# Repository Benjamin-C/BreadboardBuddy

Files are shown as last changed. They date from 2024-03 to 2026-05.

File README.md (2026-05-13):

# Breadboard Buddy

An RP2040 microcontroller designed to fit neatly on the end of a breadboard

Important: Some software features listed here are not yet implemented. Run the `help` command to see the commands actually implemented in the current firmware version

# Specs
### Power
| Parameter | | Min | Typ | Max | Unit |
|---|-----|-----|-----|-----|---|
| Input Voltage  | USB | | 5 | | V |
| | EXT | 5 | 12  | 30  | V |
| | AIN | 0 | | 3.3 | V |
| | GPIO| 0 | | 3.3 | V |
| Input Current  | USB | | | 0.5 | A |
| | EXT | | | 2 | A |
| | GPIO| | | 10  | mA |
| Output Voltage | 3v3 | | 3.3 | | V |
| | 3v3A| | 3.3 | | V |
| | GPIO| 0 | | 3.3 | V |
| Output Current | 3v3 | 0.5 | | 2 | A |
| | GPIO| | | 10  | mA |

### System
* Microcontroller: RP2040
* Flash: 2MB

### Peripherals
* 16 GPIO pins capable of input with pull up/down and constant or PWM output.
* 4 analog inputs
* 1 LED connected to GPIO16
* 1 barrel jack switch connected to GPIO17
* 1 button connected to GPIO18

# Setup

## Wiring
Connect the Breadboard Buddy to a breadboard's power rails. Ensure that the positive and negative outputs go to the red and blue sides of each rail. Connect external circuitry to the GPIO or analog pins. If you are doing a lot of analog circuitry, you may with to configure the right rail to be disconnected and manually connect 3v3A there instead. If you are using any voltage higher than 3.3V in your circuit, ensure that it can not reach any of the input pins to the microcontroller.

Connect the USB port of the Breadboard Buddy to your computer, and open and connect your favorite serial monitor.

## Configuration

The right power rail can be configured to output 3v3, EXT, or USB by moving the jumper near the barrel jack. Removing this jumper disconnects that power rail.

Each pin that you want to be an output will have to be explicitly set up as such by using the `mode` command. GPIO pins can be set up as digital inputs or outputs, or PWM outputs. Analog pins can only be set up as analog inputs.

## Firmware
The Breadboard Buddy firmware runs on CircuitPython. To Install it:
1. Download CircuitPython for the Raspberry Pi Pico from https://circuitpython.org/board/raspberry_pi_pico/
2. Connect the Breadboard Buddy to your computer. Disconnect anything else from the Breadboard Buddy.
3. Press and hold the `Reset` button, then press and hold the `Boot` button
4. Release the `Reset` button then release the `Boot` button.
5. The Breadboard buddy should appear as a USB mass storage device named `RPI-RP2`. If this does not happen, try steps 3 and 4 again, waiting longer between actions. If the issue precisest, you have an issue with your hardware.
6. Copy CircuitPython file `adafruit-circuitpython-raspberry_pi_pico-en_US-<version>.uf2` onto the Breadboard Buddy. It should reboot when this is complete.
7. The Breadboard Buddy should now appear as a USB mass storage device named `CIRCUITPY`. If this does not happen, try again from step 3. If the issue precisest, you have an issue with your hardware.
8. Copy `code.py` from `firmware` onto the Breadboard Buddy. The Breadboard Buddy should blink its light several times. You have now installed the Breadboard Buddy firmware.

It is possible to run other software on the Breadboard Buddy either through CircuitPython or by flashing it yourself. This guide will not help you with that.

# Usage

The Breadboard Buddy is interfaced with by sending commands over serial and reading their response.

## Command Types
There are two forms of commands, questions and instructions.
### Instructions
An instruction tells the Breadboard Buddy to do something. This could be to change a configuration field, or set an output value. Most instructions will take the form `<instruction> <field> <value>`. If no value is provided, the command will be assumed to be a question.
### Questions
Questions are asked in the form `<question>[?] <field>`. While the question mark is not required, it is encouraged since any command given with a question mark will be interpreted as a question, even if values are given (in which case they will be ignored).

## Pins
### Pin Fields
For commands that take a pin as a field, there are several ways the pin can be specified. 
#### By number
Pins can be specified by number. Digital pins are 0-15. Analog pins are  ain0-ain4. Example: `5`, `12`, `3`, `ain2`
#### By Name
Pins can also be set up to be identified by a name. Names can be used in place of numbers. Names must be unique for each pin, and each pin can only have 1 alias. Names may contain letters and numbers, but no dashes, spaces, or other characters. Names must start with a letter. Names are not case sensitive, but the given case is stored. Example: `LED`, `BitClk`, `Q`, `Addr2`
#### By range
Pins can be specified by a range. Ranges are specified by a start pin then a dash then the end pin. Ranges are inclusive. The range will be evaluated in the order given. If names are used, they will be converted to pin numbers before the range is calculated. Names and numbers can be mixed. You may not mix analog and digital pins in a range. Example: `0-7`, `ADDR0-ADDR4`, `ain0-ain3`
#### By list
Pins can be specified by a list. Lists are comma separated. The command will execute on each pin in the order they are specified. Names and numbers can be mixed. Example: `1,2,8,4`, `ADDR0,ADDR1,ADDR2`

### Pin States

#### Digital
Digital pins can be either high, low, or a PWM value. When specifying the state of a pin, you can use

* `H`, `HIGH`, `1`, `ON` for high output
* `L`, `LOW`, `0`, `OFF` for low output
* Numbers from 0.000 to 1.000 (only if the pin is configured as PWM)

Note that `ON` and `OFF` should be avoided if you are using active low logic to avoid confusion since they do not reverse for active low signals.

#### Analog
Analog pins will return the voltage on that pin in the form `#.###`. Analog pins can not be set to values.

## Commands

Some commands have a short form and a long form. The short form is the part of the long form shown in CAPS. Either form is acceptable. No part of a command is case sensitive. Multiple fields are separated by spaces. Commands listed with a ? are read only. 

All commands are in the form `<command>[?] <pin(s)> [field(s)]`

| Command | Allowed Fields | Action
|---|---|-
| Mode | OUTPUT,INPUT,PULLUP,PULLDOWN,PWM | Sets/gets the mode of a digital pin
| Name | Pin name | Sets/gets the name of a digital or analog pin
| Digital | Digital pin states | Sets/gets value of a digital pin
| Analog? | none | Gets the value of an analog pin
| Read? | none | Reads the value on any pin
| Bin | `0`,`1` | Sets/gets the value of pins in binary

### Mode
The mode command sets up digital pins. `OUTPUT` sets the pin up as an output and sets the pin's value to low. `INPUT`,`PULLUP`, and `PULLDOWN` set up the pin as an input with the pull if specified. `PWM` sets up the pin as a PWM output pin. If queried, returns the configuration of the pin.

### Name
Handles aliases for pins. The first field is either `D` or `A` to specify if you are using a digital or an analog pin. The second field is the new name for that pin. Names may only contain letters and numbers, and must contain at least one letter. If the pin is specified by name, the pin will be renamed. If queried by number, the name of that pin is returned. If queried by name, the number of that pin is returned.

### Digital
The digital command interacts with digital pins. The field is the value to set. Setting a PWM pin to high or low will result in 100% or 0% duty cycle respectively. Attempting to set input pins has no effect. Querying output pins returns their set value. Querying input pins returns the value read from that pin. The result of the query will be `H`, `L`, or `0.###`

### Analog
Queries analog pins. The Analog command is always assumed to be a query. The result of the query will be `0.###`

### Read
Reads the value of one or more pins. You can mix analog and digital pins. The Read command is always assumed to be a query. The result of the query will be `H`, `L`, or `0.###`

### Binary
Gets the digital value of pins. The result will be `0` or `1`. If an analog pin is specified, the output will be `0` if the voltage is less than half, `1` otherwise. This command can also be used to set the value of digital pins; in this case it will be treated as an alias of the Digital command.

# The Power System

## Power Input

The Breadboard Buddy can be powered from USB, an external power supply, or both.

### USB
You can power the board using the USB connector you use to communicate with it. The USB port does not support USB-PD. The USB port is protected by a 500mA polyfuse as well as a diode allowing safe connection of both power sources simultaneously.
* 500mA total limit form the USB port
* 500mA 3v3 limit

### EXT
You can also power the board form an external power supply with a 5.5x2.1mm center positive barrel jack. You can supply any voltage from 5V to 30V. This jack is protected by a 2A polyfuse and a diode.
* 2A total limit from the barrel jack
* 2A limit 3v3 limit

## Power Output
The left power rail is always powered from 3v3. The right power rail can be configured to be powered from 3v3, EXT, or USB, or it can be left unpowered. This allows you to provide your own power source to this rail. This rail can be set to USB even if EXT is present.

## Power Domains

Termanology:
* A "rail" is a physical power distribution system found on the side of a breadboard.
* A "domain" is a power net on the PCB. Domains can be connected to rails.

The Breadboard Buddy has 5 power domains summarized in this table and described in more detail below.

| Domain | Description | Source | Voltage | Current | Notes |
|---|---|---|---|---|---|
| 3v3 (3v3D) | Digital supply | VBUS | 3.3V | Max 2A  | |
| EXT | External input | 5.5x2.1mm Barrel jack | 5-30V | Max 2A polyfused | |
| 3v3A | Analog supply  | VBUS | 3.3V | 150mA | For use only in analog circuits 
| USB | USB input | USB-C port | 5V | 500mA polyfused | Limits 3v3 to 500mA if used
| VBUS | System power | Higher of EXT or USB  | 5-30V | 2A or 500mA | Not accessible externally

### 3v3 (aka 3v3D)
This is the main 3.3V power domain. It is powered by a switching voltage regulator from VBUS. It is used for the digital parts of the board, as well as the 3.3V output on the left power rails, and optionally the right power rails. When powered from EXT, it can supply up to 2A, although this may be limited by the board's power source. When powered from USB, it can supply up to 500mA. This domain should be used for all external digital circuitry.

### EXT
This is the external power source provided through the barrel jack. It is used to supply the voltage regulators if it is present. It can also be sent to the right power rails if desired. It has a total capacity of 2A which may be limited by the external power supply, and it is shared between VBUS and the breadboard power rails.

### 3v3A
This is the analog supply. It is powered by a linear voltage regulator. It is used for the analog parts of the RP2040, and is made available for external analog circuitry on the analog pin header. This domain should be used for all external analog circuitry to reduce power supply noise.

### USB
This is the USB power input. It is used to supply the voltage regulators if EXT is not present. It can also be sent to the right power rails if desired. It has a total capacity of 500mA which is shared between the rails and VBUS if EXT is not present.

### VBUS
This is the power domain that powers the voltage regulators. It is powered by EXT if it is present, or USB. It is not accessible externally.

# Credits
* The center positive symbol came from [Wikipedia](https://en.m.wikipedia.org/wiki/File:Polarity_marking_center_positive.svg). The image is in the public domain.
* The firmware is built on top of [CircuitPython](https://circuitpython.org/)

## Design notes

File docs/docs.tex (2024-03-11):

\documentclass[12pt,letterpaper]{article}

% My defaults
\usepackage[]{preamble}

% \renewcommand\thesubsection{\alph{subsection}.}
% \renewcommand\thesection{\arabic{section}.}

% Proper underscores
% (1) choose a font that is available as T1
\usepackage{lmodern}
% (2) specify encoding
\usepackage[T1]{fontenc}
% (3) load symbol definitions
\usepackage{textcomp}

\usepackage{tabularx}

% Remove labels from parts. Might leave white space :(
% Also reset section numbering
\renewcommand{\partname}{\setcounter{section}{0}Problem}
% \renewcommand{\partname}{\setcounter{section}{0}\vspace{-1.5em}Problem}
\renewcommand{\thepart}{\arabic{part}}

\usepackage[explicit]{titlesec}

\lstset{
    breaklines,
    style=,
    language=,
    postbreak=,
    % language=python,
    % xleftmargin=0pt,
    % xrightmargin=0pt,
    framexleftmargin=0pt,
    framexrightmargin=0pt,
    %   basicstyle={\fontsize{10pt}{12pt}\ttfamily},
    %   columns=flexible,
    %   keepspaces=true,
    %   showstringspaces=false,
    %   identifierstyle=\color[rgb]{0.17,0.39,0.85},
    %   keywordstyle=\color[rgb]{0.86,0.15,0.37},
    %   commentstyle=\color[rgb]{0.5,0.5,0.5},
    frame=ltrb,
    numbers=none, 
    % numberstyle=\color{blue}\small, 
    % numbersep=8pt,
    backgroundcolor=\color[rgb]{0.95,0.99,0.99},
    %   tabsize=4,
}

\let\oldbf\bf
\renewcommand{\bf}[1]{
    {\oldbf #1}
}

\usepackage{chngcntr}
\counterwithin{table}{section}
\counterwithin{table}{subsection}

\usepackage{tcolorbox}
\newtcbox{\codebox}{
    nobeforeafter,
    tcbox raise base,
    left=3pt,
    right=3pt,
    top=3pt,
    bottom=2pt,
    arc=1pt,
    boxsep=0pt,
    colback=gray!10,
    colframe=gray!50,
    boxrule=0.5pt,
}
\MakeRobust\codebox

\let\oldcode\code
\renewcommand{\code}[1]{
    \hspace{-0.4em}\codebox{\oldcode{#1}}\hspace{-0.4em}
}

\newtcbox{\excodebox}{
    nobeforeafter,
    tcbox raise base,
    left=5pt,
    right=5pt,
    top=4pt,
    bottom=3pt,
    arc=1pt,
    boxsep=0pt,
    colback=blue!80!red!90!white,
    colframe=blue!40,
    fontupper=\color{white},
    boxrule=0.5pt,
}
\MakeRobust\excodebox

\newcommand{\excode}[1]{
    \hspace{-0.4em}\excodebox{\oldcode{#1}}\hspace{-0.4em}
}

\newcommand{\example}[2]{
    \begin{tcolorbox}[
        colback=blue!80!red!10!white,
        colframe=blue!80!red,
        arc=2pt,
        left=3pt,
        right=3pt,
        top=3pt,
        bottom=2pt,
        boxrule=0.5pt,
        title={Example #1}
    ]
    #2
    \end{tcolorbox}
}

\newcommand{\examplecmd}[3]{
    \example{}{
        \renewcommand*{\arraystretch}{1.5}
        \begin{tabular}{p{0.15\textwidth}p{0.75\textwidth}}
            \textbf{Task} & #1 \\
            \textbf{Command} &  \code{#2} \\
            \textbf{Response} & \code{#3}
        \end{tabular}
    }
}

\titleformat{\section}[block]
    {}{}{0em}
    {\begin{tcolorbox}
        \thesection. \hspace*{\fill} #1 \hspace*{\fill}
    \end{tcolorbox}}

\usepackage{booktabs}

\let\oldhref\href
\renewcommand{\href}[2]{
    {\color{blue}\underline{\oldhref{#1}{#2}}}
}

\let\oldurl\url
\renewcommand{\url}[1]{
    {\color{blue}\underline{\oldurl{#1}}}
}

\newcommand{\bolditem}[1]{
    \par
    \vspace{0.5em}
    \noindent\textbf{#1: }
}

\newcommand{\thickrule}{\noalign{\hrule height 1.2pt}}

\title{\huge Breadboard Buddy}
\author{{\Large Benjamin Crall}}
\date{Rev 0.1 - March 10}

% The stuffs
\begin{document}
\maketitle

\section{Introduction}

An RP2040 microcontroller designed to fit neatly on the end of a breadboard

\section{Specs}

\subsection{Power}
\begin{table}[H]
    \centering
    \begin{tabular}{|cc|c|c|c|c|}\hline
        Parameter      &      & Min & Typ & Max & Unit \\\hline
        Input Voltage  & USB  &     & 5   &     & V    \\
                       & EXT  & 5   & 12  & 30  & V    \\
                       & AIN  & 0   &     & 3.3 & V    \\
                       & GPIO & 0   &     & 3.3 & V    \\\hline
        Input Current  & USB  &     &     & 0.5 & A    \\
                       & EXT  &     &     & 2   & A    \\
                       & GPIO &     &     & 10  & mA   \\\hline
        Output Voltage & 3v3  &     & 3.3 &     & V    \\
                       & 3v3A &     & 3.3 &     & V    \\
                       & GPIO & 0   &     & 3.3 & V    \\\hline
        Output Current & 3v3  & 0.5 &     & 2   & A    \\
                       & 3v3A &     &     & 300 & mA   \\
                       & GPIO &     &     & 10  & mA   \\\hline
    \end{tabular}
\end{table}

\subsection{System}
\begin{itemize}
    \item Microcontroller: RP2040
    \item Flash: 2MB
\end{itemize}

\subsection{Peripherals}
\begin{itemize}
    \item 16 GPIO pins capable of input with pull up/down and constant or PWM output.
    \item 4 analog inputs
    \item 1 LED connected to GPIO16
    \item 1 barrel jack switch connected to GPIO17
    \item 1 button connected to GPIO18
\end{itemize}

\section{Setup}

\subsection{Wiring}
Connect the Breadboard Buddy to a breadboard's power rails. Ensure that the positive and negative outputs go to the red and blue sides of each rail. Connect external circuitry to the GPIO or analog pins. If you are doing a lot of analog circuitry, you may with to configure the right rail to be disconnected and manually connect 3v3A there instead. If you are using any voltage higher than 3.3V in your circuit, ensure that it can not reach any of the input pins to the microcontroller.

Connect the USB port of the Breadboard Buddy to your computer, and open and connect your favorite serial monitor.

\subsection{Configuration}

The right power rail can be configured to output 3v3, EXT, or USB by moving the jumper near the barrel jack. Removing this jumper disconnects that power rail.

Each pin that you want to be an output will have to be explicitly set up as such by using the `mode` command. GPIO pins can be set up as digital inputs or outputs, or PWM outputs. Analog pins can only be set up as analog inputs.

\subsection{Firmware}
The Breadboard Buddy firmware runs on CircuitPython. To Install it:
\begin{enumerate}
    \item Download CircuitPython for the Raspberry Pi Pico from \\\url{https://circuitpython.org/board/raspberry_pi_pico/}
    \item Connect the Breadboard Buddy to your computer. Disconnect anything else from the Breadboard Buddy.
    \item \label{step:install:off} Press and hold the \code{Reset} button, then press and hold the \code{Boot} button
    \item \label{step:install:on} Release the \code{Reset} button then release the \code{Boot} button.
    \item The Breadboard buddy should appear as a USB mass storage device named \code{RPI-RP2}. If this does not happen, try steps \ref{step:install:off} and \ref{step:install:on} again, waiting longer between actions. If the issue precisest, you have an issue with your hardware.
    \item Copy CircuitPython file you just downloaded onto the Breadboard Buddy. The file should be \code{adafruit-circuitpython-raspberry\_pi\_pico-en\_US-<version>.uf2}.\\The Breadboard Buddy should reboot when the upload is complete.
    \item The Breadboard Buddy should now appear as a USB mass storage device named \code{CIRCUITPY}. If this does not happen, try again from step \ref{step:install:off}. If the issue precisest, you have an issue with your hardware.
    \item  Copy \code{code.py} from \code{firmware} onto the Breadboard Buddy. The Breadboard Buddy should blink its light several times. You have now installed the Breadboard Buddy firmware.
\end{enumerate}
\noindent
It is possible to run other software on the Breadboard Buddy either through CircuitPython or by flashing it yourself. This guide will not help you with that.

\section{Usage}
The Breadboard Buddy is interfaced with by sending commands over serial and reading their response.

\subsection{Pins}
\subsubsection{Pin Fields}
For commands that take a pin as a field, there are several ways the pin can be specified.

\bolditem{By number}
Pins can be specified by number. Digital pins are 0-15. Analog pins are ain0-ain4. Example: \code{5}, \code{12}, \code{3}, \code{ain2}

\bolditem{By Name}
Pins can also be set up to be identified by a name. Names can be used in place of numbers. Names must be unique for each pin, and each pin can only have 1 alias. Names may contain letters and numbers, but no dashes, spaces, or other characters. Names must start with a letter. Names are not case sensitive, but the given case is stored. Example: \code{LED}, \code{BitClk}, \code{Q}, \code{Addr2}

\bolditem{By range}
Pins can be specified by a range. Ranges are specified by a start pin then a dash then the end pin. Ranges are inclusive. The range will be evaluated in the order given. If names are used, they will be converted to pin numbers before the range is calculated. Names and numbers can be mixed. You may not mix analog and digital pins in a range. Example: \code{0-7}, \code{ADDR0-ADDR4}, \code{ain0-ain3}

\bolditem{By list}
Pins can be specified by a list. Lists are comma separated. The command will execute on each pin in the order they are specified. Names and numbers can be mixed. Example: \code{1,2,8,4}, \code{ADDR0,ADDR1,ADDR2}

\subsubsection{Pin States}

\bolditem{Digital}
Digital pins can be either high, low, or a PWM value. When specifying the state of a pin, you can use
\begin{itemize}
    \item \code{H}, \code{HIGH}, \code{1}, \code{ON} for high output
    \item \code{L}, \code{LOW}, \code{0}, \code{OFF} for low output
    \item Numbers from 0.000 to 1.000 (only if the pin is configured as PWM)
\end{itemize}
Note that \code{ON} and \code{OFF} should be avoided if you are using active low logic to avoid confusion since they do not reverse for active low signals.

\bolditem{Analog}
Analog pins will return the voltage on that pin in the form \code{\#.\#\#\#}. Analog pins can not be set to values.

\subsection{Commands}
There are two forms of commands, questions and instructions.

\bolditem{Instructions}
An instruction tells the Breadboard Buddy to do something. This could be to change a configuration field, or set an output value. Most instructions will take the form \code{<instruction> <field> <value>}. If no value is provided, the command will be assumed to be a question.

\bolditem{Questions}
Questions are asked in the form \code{<question>[?] <field>}. While the question mark is not required, it is encouraged since any command given with a question mark will be interpreted as a question, even if values are given (in which case they will be ignored).
\vspace{1em}

Some commands have a short form and a long form. The short form is the part of the long form shown in CAPS. Either form is acceptable. No part of a command is case sensitive. Multiple fields are separated by spaces. Commands listed with a \code{?} are read only. 

\begin{table}[H]
    \centering
    \begin{tabular}{|p{0.2\linewidth}|p{0.25\linewidth}|p{0.45\linewidth}|}\hline
        Command & Fields             & Action \\\thickrule
        Mode    & Pin mode           & Sets/gets the mode of a digital pin \\\hline
        Name    & Pin name           & Sets/gets the name of a pin \\\hline
        Digital & Digital pin states & Sets/gets value of a digital pin(s) \\\hline
        Analog? & none               & Gets the value of an analog pin(s) \\\hline
        Read?   & none               & Gets the value on any pin(s) \\\hline
        Bin     & `0`,`1`            & Sets/gets the value of pin(s) in binary\\\hline
    \end{tabular}
\end{table}

\subsubsection{Mode}
The mode command sets the mode of the digital pins. If queried, returns the configuration of the pin. The options for mode are:
\bolditem{\texttt{OUTPUT}} sets the pin up as an output and sets the pin's value to low. Output pins can can drive their value to either \code{HIGH} or \code{LOW}.
\bolditem{\texttt{INPUT}} sets the pin up as an input pin without any pull. Input pins are left floating and must be driven externally for constant results.
\bolditem{\texttt{PULLUP}} sets the pin up as an input pin with a weak pull up. The pin will read as high unless something externally drives it low.
\bolditem{\texttt{PULLDOWN}} sets the pin up as an input pin with a weak pull up. The pin will read as low unless something externally drives it high.
\bolditem{\texttt{PWM}} sets the pin up as a \href{https://en.wikipedia.org/wiki/Pulse-width\_modulation}{Pulse Width Modulated} output. PWM outputs can output psudo-analog values by alternately driving the output high and low and changing the ratio of high to low.
\examplecmd{Sets up pin 4 as an output}{mode 4 OUTPUT}{OK}

\subsubsection{Name}
Handles aliases for pins. The first field is the new name for that pin. Names may only contain letters and numbers, and must contain at least one letter. If the pin is specified by name, the pin will be renamed. Only a single pin may be specified when setting a name. If queried by number, the name of that pin is returned. If queried by name, the number of that pin is returned.
\examplecmd{Sets the alias for pin 14 to \code{CLK}}{name 14 CLK}{OK}
\examplecmd{Gets the alias for pin 14}{name? 14}{CLK}

\subsubsection{Digital}
The digital command interacts with digital pins. The field is the value to set. Setting a PWM pin to high or low will result in 100\% or 0\% duty cycle respectively. Attempting to set input pins has no effect. Querying output pins returns their set value. Querying input pins returns the value read from that pin. The result of the query will be \code{H}, \code{L}, or \code{0.\#\#\#}
\examplecmd{Get the values from pins 8-11}{digital? 8-11}{HLHH}
\examplecmd{Set the values from pins 8-11 to LHHL}{digital 8-11 L,H,H,L}{OK}

\subsubsection{Analog}
Queries analog pins. The Analog command is always assumed to be a query. The result of the query will be the voltage on the analog pin in the form \code{\#.\#\#\#}
\examplecmd{Get the values from pins ain2}{analog? ain2}{2.851}

\subsubsection{Read}
Reads the value of one or more pins. You can mix analog and digital pins. The Read command is always assumed to be a query. The result of the query will be the same as would be returned from \code{Digital?} and \code{Analog?} for each pin.
\examplecmd{Get the values from pins 0-5}{read? 5-0}{HHLHLH}

\subsubsection{Binary}
\bolditem{Question}
Gets the digital value of pins. The result will be \code{0} or \code{1}. If an analog pin is specified, the output will be \code{0} if the voltage is less than half of the maximum, \code{1} otherwise. An optional field specifies the number format, either \code{DEC}, \code{HEX}, or \code{BIN} (default). The number will be padded so that the number of characters won't change depending on the values of the pins.
\bolditem{Instruction}
Sets the pin(s) based on the binary value of the field value. The pins are specified MSB first. If the field has more bits than the number of pins, the most significant bits will be truncated. If the field has less bits than the number of pins, the value will be padded on the MSB end. An optional second field specifies the number format, either \code{DEC}, \code{HEX}, or \code{BIN} (default).
\examplecmd{Get the values from pins 0-5 as a binary number where 0 is the LSB}{binary? 5-0}{110101}
\examplecmd{Read the binary encoded number on pins 0-3 in hex}{binary? 3-0 HEX}{C}
\examplecmd{Set the binary encoded number on pins 0-3 to 0x5}{binary 3-0 5 HEX}{OK}

\section{Theory Of Operation}
\subsection{The Power System}

\subsubsection{Terminology}
\par\noindent
\textbf{Rails} are physical power distribution systems found on the sides of a breadboard.
\par\noindent
\textbf{Domains} are the power nets on the PCB. Some domains can connect to the rails.

\subsubsection{Power Input}
\bolditem{USB}
You can power the board using the USB connector you use to communicate with it. The USB port does not support USB-PD. The USB port is protected by a 500mA polyfuse as well as a diode allowing safe connection of both power sources simultaneously. When using USB as the power source, you should limit 3.3V to 500mA.
\bolditem{EXT}
You can also power the board form an external power supply with a 5.5x2.1mm center positive barrel jack. You can supply any voltage from 5V to 30V. This jack is protected by a 2A polyfuse and a diode. When using the barrel jack, the full 2A output of the 3v3 regulator is available as long as the external power supply can support that much power.

\subsubsection{Power Output}
The left power rail is always powered from 3v3. The right power rail can be configured to be powered from 3v3, EXT, or USB, or it can be left unpowered. This allows you to provide your own power source to this rail. This rail can be set to USB even if EXT is present.

\subsubsection{Power Domains}

\begin{table}[H]
    \centering
    \begin{tabular}{|llllll|}\hline
        Domain     & Description    & Source      & Voltage & Current     & Curret Limiter \\\hline
        3v3        & Digital supply & VBUS        & 3.3V    & 2A or 500mA & Reg IC         \\
        EXT        & External input & Barrel jack & 5-30V   & Max 2A      & 2A Polyfuse    \\
        3v3A       & Analog supply  & VBUS        & 3.3V    & 300mA       & Reg ID         \\
        USB        & USB input      & USB-C port  & 5V      & 500mA       & 500mA Polyfuse \\
        VBUS       & System power   & EXT or USB  & 5-30V   & 2A or 500mA &                \\\hline
    \end{tabular}
\end{table}

\bolditem{3v3 (aka 3v3D)}
This is the main 3.3V power domain. It is powered by a switching voltage regulator from VBUS. It is used for the digital parts of the board, as well as the 3.3V output on the left power rails, and optionally the right power rails. When powered from EXT, it can supply up to 2A, although this may be limited by the board's power source. When powered from USB, it can supply up to 500mA. This domain should be used for all external digital circuitry.

\bolditem{EXT}
This is the external power source provided through the barrel jack. It is used to supply the voltage regulators if it is present. It can also be sent to the right power rails if desired. It has a total capacity of 2A which may be limited by the external power supply, and it is shared between VBUS and the breadboard power rails.

\bolditem{3v3A}
This is the analog supply. It is powered by a linear voltage regulator. It is used for the analog parts of the RP2040, and is made available for external analog circuitry on the analog pin header. This domain should be used for all external analog circuitry to reduce power supply noise.

\bolditem{USB}
This is the USB power input. It is used to supply the voltage regulators if EXT is not present. It can also be sent to the right power rails if desired. It has a total capacity of 500mA which is shared between the rails and VBUS if EXT is not present.

\bolditem{VBUS}
This is the power domain that powers the voltage regulators. It is powered by EXT if it is present, or USB. It is not accessible externally.

\section{Credits}
\begin{itemize}
    \item The center positive symbol came from \href{https://en.m.wikipedia.org/wiki/File:Polarity_marking_center_positive.svg}{Wikipedia}. The image is in the public domain.
    \item The firmware is built on top of \href{https://circuitpython.org/}{CircuitPython}
\end{itemize}
\end{document}

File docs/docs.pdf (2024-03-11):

# Breadboard Buddy

## Benjamin Crall

### Rev 0.1 - March 10

1. Introduction

An RP2040 microcontroller designed to fit neatly on the end of a breadboard

2. Specs

### 2.1 Power

Parameter | Min | Typ | Max | Unit
Input Voltage USB EXT AIN GPIO | 5 0 0 | 5 12 | 30 3.3 3.3 | V V V V
Input Current USB EXT GPIO | | | 0.5 2 10 | A A mA
Output Voltage 3v3 3v3A GPIO | 0 | 3.3 3.3 | 3.3 | V V V
Output Current 3v3 3v3A GPIO | 0.5 | | 2 300 10 | A mA mA

### 2.2 System

- Microcontroller: RP2040
- Flash: 2MB

### 2.3 Peripherals

- 16 GPIO pins capable of input with pull up/down and constant or PWM output.
- 4 analog inputs
- 1 LED connected to GPIO16
- 1 barrel jack switch connected to GPIO17
- 1 button connected to GPIO18
3. Setup

### 3.1 Wiring

Connect the Breadboard Buddy to a breadboard’s power rails. Ensure that the positive and negative outputs go to the red and blue sides of each rail. Connect external circuitry to the GPIO or analog pins. If you are doing a lot of analog circuitry, you may with to configure the right rail to be disconnected and manually connect 3v3A there instead. If you are using any voltage higher than 3.3V in your circuit, ensure that it can not reach any of the input pins to the microcontroller.
Connect the USB port of the Breadboard Buddy to your computer, and open and connect your favorite serial monitor.

### 3.2 Configuration

The right power rail can be configured to output 3v3, EXT, or USB by moving the jumper near the barrel jack. Removing this jumper disconnects that power rail.
Each pin that you want to be an output will have to be explicitly set up as such by using the ‘mode‘ command. GPIO pins can be set up as digital inputs or outputs, or PWM outputs. Analog pins can only be set up as analog inputs.

### 3.3 Firmware

The Breadboard Buddy firmware runs on CircuitPython. To Install it:

1. Download CircuitPython for the Raspberry Pi Pico from https://circuitpython.org/board/raspberry_pi_pico/
2. Connect the Breadboard Buddy to your computer. Disconnect anything else from the Breadboard Buddy.
3. Press and hold the Reset button, then press and hold the Boot button

4. Release the Reset button then release the Boot button.
5. The Breadboard buddy should appear as a USB mass storage device named RPI-RP2 . If this does not happen, try steps 3 and 4 again, waiting longer between actions. If the issue precisest, you have an issue with your hardware.
6. Copy CircuitPython file you just downloaded onto the Breadboard Buddy. The file should be adafruit-circuitpython-raspberry_pi_pico-en_US-<version>.uf2 . The Breadboard Buddy should reboot when the upload is complete.
7. The Breadboard Buddy should now appear as a USB mass storage device named CIRCUITPY . If this does not happen, try again from step 3. If the issue precisest, you have an issue with your hardware.
8. Copy code.py from firmware onto the Breadboard Buddy. The Breadboard Buddy should blink its light several times. You have now installed the Breadboard Buddy firmware.

It is possible to run other software on the Breadboard Buddy either through CircuitPython or by flashing it yourself. This guide will not help you with that.

4. Usage

The Breadboard Buddy is interfaced with by sending commands over serial and reading their response.

### 4.1 Pins

### 4.1.1 Pin Fields

For commands that take a pin as a field, there are several ways the pin can be specified.

By number: Pins can be specified by number. Digital pins are 0-15. Analog pins are ain0-ain4. Example: 5 , 12 , 3 , ain2

By Name: Pins can also be set up to be identified by a name. Names can be used in place of numbers. Names must be unique for each pin, and each pin can only have 1 alias. Names may contain letters and numbers, but no dashes, spaces, or other characters. Names must start with a letter. Names are not case sensitive, but the given case is stored. Example: LED , BitClk , Q , Addr2

By range: Pins can be specified by a range. Ranges are specified by a start pin then a dash then the end pin. Ranges are inclusive. The range will be evaluated in the order given. If names are used, they will be converted to pin numbers before the range is calculated.

Names and numbers can be mixed. You may not mix analog and digital pins in a range. Example: 0-7 , ADDR0-ADDR4 , ain0-ain3

By list: Pins can be specified by a list. Lists are comma separated. The command will execute on each pin in the order they are specified. Names and numbers can be mixed. Example: 1,2,8,4 , ADDR0,ADDR1,ADDR2

### 4.1.2 Pin States

Digital: Digital pins can be either high, low, or a PWM value. When specifying the state of a pin, you can use

- H , HIGH , 1 , ON for high output
- L , LOW , 0 , OFF for low output
- Numbers from 0.000 to 1.000 (only if the pin is configured as PWM)

Note that ON and OFF should be avoided if you are using active low logic to avoid confusion since they do not reverse for active low signals.

Analog: Analog pins will return the voltage on that pin in the form #.### . Analog pins can not be set to values.

### 4.2 Commands

There are two forms of commands, questions and instructions.

Instructions: An instruction tells the Breadboard Buddy to do something. This could be to change a configuration field, or set an output value. Most instructions will take the form <instruction> <field> <value> . If no value is provided, the command will be assumed to be a question.

Questions: Questions are asked in the form <question>[?] <field> . While the question mark is not required, it is encouraged since any command given with a question mark will be interpreted as a question, even if values are given (in which case they will be ignored).

Some commands have a short form and a long form. The short form is the part of the long form shown in CAPS. Either form is acceptable. No part of a command is case sensitive. Multiple fields are separated by spaces. Commands listed with a ? are read only.

Command | Fields | Action
Mode | Pin mode | Sets/gets the mode of a digital pin
Name | Pin name | Sets/gets the name of a pin
Digital | Digital pin states | Sets/gets value of a digital pin(s)
Analog? | none | Gets the value of an analog pin(s)
Read? | none | Gets the value on any pin(s)
Bin | ‘0‘,‘1‘ | Sets/gets the value of pin(s) in binary

### 4.2.1 Mode

The mode command sets the mode of the digital pins. If queried, returns the configuration of the pin. The options for mode are:

OUTPUT: sets the pin up as an output and sets the pin’s value to low. Output pins can can drive their value to either HIGH or LOW .

INPUT: sets the pin up as an input pin without any pull. Input pins are left floating and must be driven externally for constant results.

PULLUP: sets the pin up as an input pin with a weak pull up. The pin will read as high unless something externally drives it low.

PULLDOWN: sets the pin up as an input pin with a weak pull up. The pin will read as low unless something externally drives it high.

PWM: sets the pin up as a Pulse Width Modulated (https://en.wikipedia.org/wiki/Pulse-width_modulation) output. PWM outputs can output psudo-analog values by alternately driving the output high and low and changing the ratio

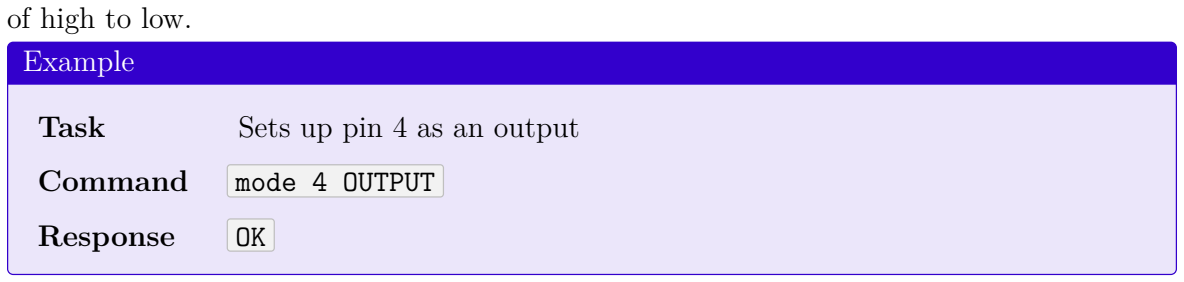
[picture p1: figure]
of high to low.; Example; Task; Sets up pin 4 as an output; Command; mode 4 OUTPUT; Response

### 4.2.2 Name

Handles aliases for pins. The first field is the new name for that pin. Names may only contain letters and numbers, and must contain at least one letter. If the pin is specified by name, the pin will be renamed. Only a single pin may be specified when setting a name. If queried by number, the name of that pin is returned. If queried by name, the number of that pin is returned.
Example
Task | Sets the alias for pin 14 to CLK
Command | name 14 CLK
Response | OK

Example

Task | Gets the alias for pin 14
Command | name? | 14
Response | CLK

### 4.2.3 Digital

The digital command interacts with digital pins. The field is the value to set. Setting a PWM pin to high or low will result in 100% or 0% duty cycle respectively. Attempting to set input pins has no effect. Querying output pins returns their set value. Querying input pins returns the value read from that pin. The result of the query will be H , L , or 0.### Example

Task | Get the values from pins 8-11
Command | digital? | 8-11
Response | HLHH

Example

Task | Set the values from pins 8-11 to LHHL
Command | digital 8-11 L,H,H,L
Response | OK

### 4.2.4 Analog

Queries analog pins. The Analog command is always assumed to be a query. The result of

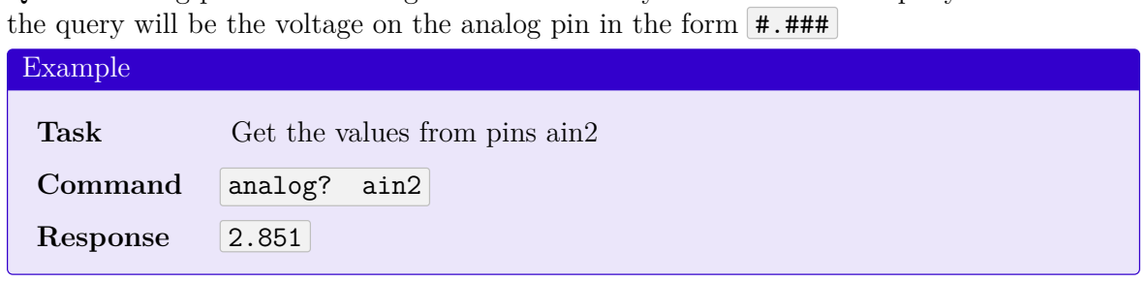
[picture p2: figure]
Example; Task; Get the values from pins ain2; Command; analog?; ain2; Response

the query will be the voltage on the analog pin in the form #.###

### 4.2.5 Read

Reads the value of one or more pins. You can mix analog and digital pins. The Read command is always assumed to be a query. The result of the query will be the same as

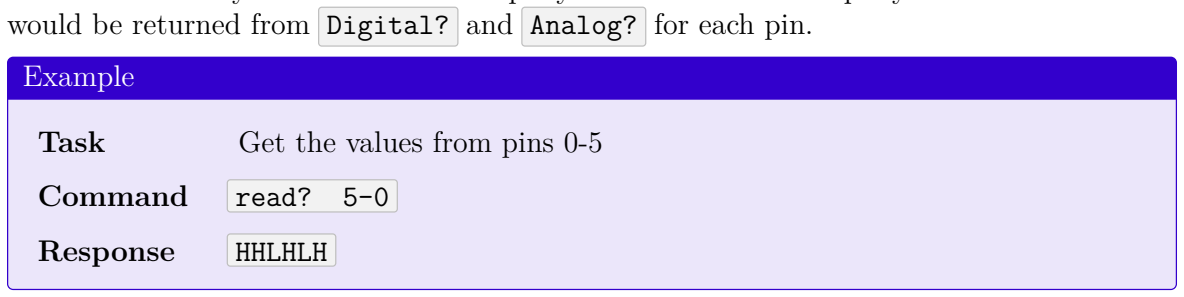
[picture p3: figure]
Example; Task; Get the values from pins 0-5; Command; read?; Response; HHLHLH

would be returned from Digital? and Analog? for each pin.

### 4.2.6 Binary

Question: Gets the digital value of pins. The result will be 0 or 1 . If an analog pin is specified, the output will be 0 if the voltage is less than half of the maximum, 1 otherwise. An optional field specifies the number format, either DEC , HEX , or BIN (default). The number will be padded so that the number of characters won’t change depending on the values of the pins.

Instruction: Sets the pin(s) based on the binary value of the field value. The pins are specified MSB first. If the field has more bits than the number of pins, the most significant bits will be truncated. If the field has less bits than the number of pins, the value will be

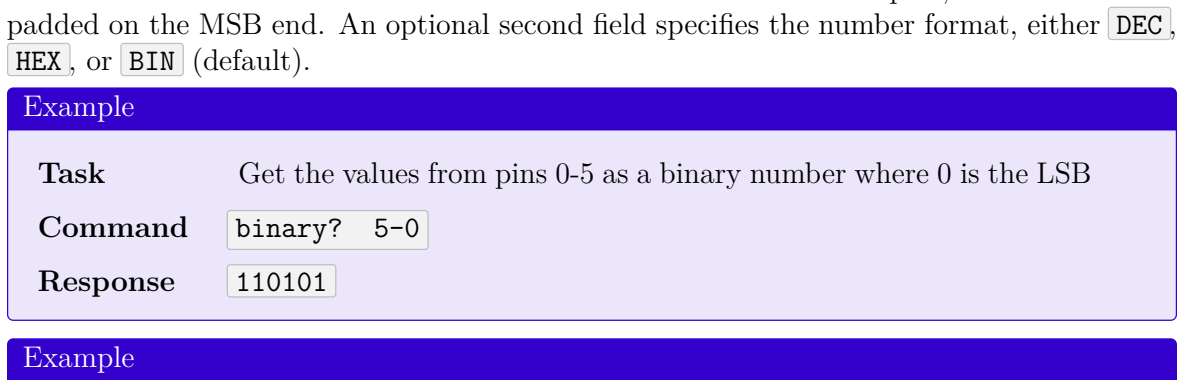
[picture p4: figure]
HEX , or BIN (default).; Example; Command; binary?; Response

padded on the MSB end. An optional second field specifies the number format, either DEC ,

Task | Get the values from pins 0-5 as a binary number where 0 is the LSB

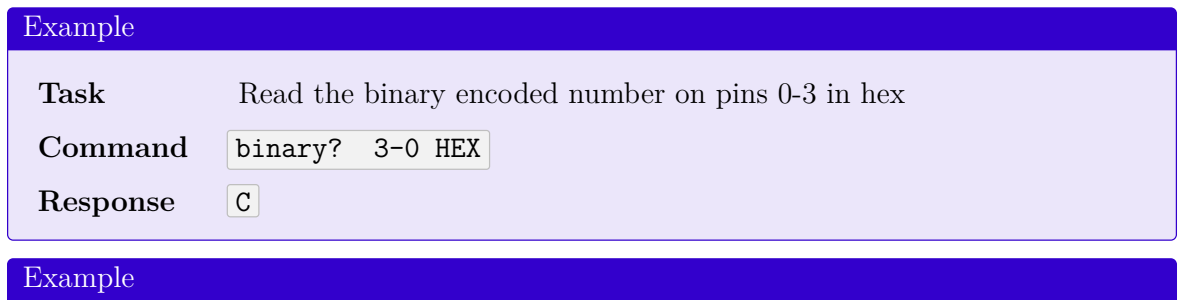
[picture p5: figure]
Command; binary?; 3-0 HEX; Response; Example

Task | Read the binary encoded number on pins 0-3 in hex

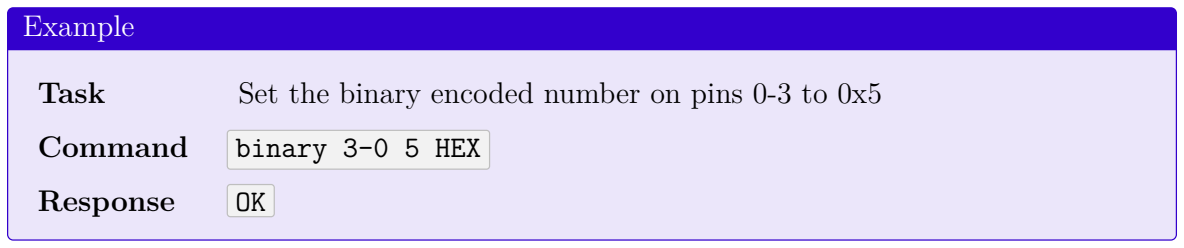
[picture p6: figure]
Command; binary 3-0 5 HEX; Response

Task | Set the binary encoded number on pins 0-3 to 0x5
5. Theory Of Operation

### 5.1 The Power System

### 5.1.1 Terminology

Rails are physical power distribution systems found on the sides of a breadboard.

Domains are the power nets on the PCB. Some domains can connect to the rails.

### 5.1.2 Power Input

USB: You can power the board using the USB connector you use to communicate with it. The USB port does not support USB-PD. The USB port is protected by a 500mA polyfuse as well as a diode allowing safe connection of both power sources simultaneously. When using USB as the power source, you should limit 3.3V to 500mA.

EXT: You can also power the board form an external power supply with a 5.5x2.1mm center positive barrel jack. You can supply any voltage from 5V to 30V. This jack is protected by a 2A polyfuse and a diode. When using the barrel jack, the full 2A output of the 3v3 regulator is available as long as the external power supply can support that much power.

### 5.1.3 Power Output

The left power rail is always powered from 3v3. The right power rail can be configured to be powered from 3v3, EXT, or USB, or it can be left unpowered. This allows you to provide your own power source to this rail. This rail can be set to USB even if EXT is present.

### 5.1.4 Power Domains

Domain Description | Source | Voltage Current | Curret Limiter
3v3 | Digital supply | VBUS | 3.3V | 2A or 500mA Reg IC
EXT | External input Barrel jack | 5-30V | Max 2A | 2A Polyfuse
3v3A | Analog supply | VBUS | 3.3V | 300mA | Reg ID
USB | USB input | USB-C port | 5V | 500mA | 500mA Polyfuse
VBUS | System power | EXT or USB 5-30V | 2A or 500mA
3v3 (aka 3v3D): | This is the main 3.3V power domain. It is powered by a switching
voltage regulator from VBUS. It is used for the digital parts of the board, as well as the 3.3V output on the left power rails, and optionally the right power rails. When powered from EXT, it can supply up to 2A, although this may be limited by the board’s power source. When powered from USB, it can supply up to 500mA. This domain should be used for all external digital circuitry.

EXT: This is the external power source provided through the barrel jack. It is used to supply the voltage regulators if it is present. It can also be sent to the right power rails if desired. It has a total capacity of 2A which may be limited by the external power supply, and it is shared between VBUS and the breadboard power rails.

3v3A: This is the analog supply. It is powered by a linear voltage regulator. It is used for the analog parts of the RP2040, and is made available for external analog circuitry on the analog pin header. This domain should be used for all external analog circuitry to reduce power supply noise.

USB: This is the USB power input. It is used to supply the voltage regulators if EXT is not present. It can also be sent to the right power rails if desired. It has a total capacity of 500mA which is shared between the rails and VBUS if EXT is not present.

VBUS: This is the power domain that powers the voltage regulators. It is powered by EXT if it is present, or USB. It is not accessible externally.

6. Credits
- The center positive symbol came from Wikipedia (https://en.m.wikipedia.org/wiki/File:Polarity_marking_center_positive.svg) . The image is in the public domain.
- The firmware is built on top of CircuitPython (https://circuitpython.org/)

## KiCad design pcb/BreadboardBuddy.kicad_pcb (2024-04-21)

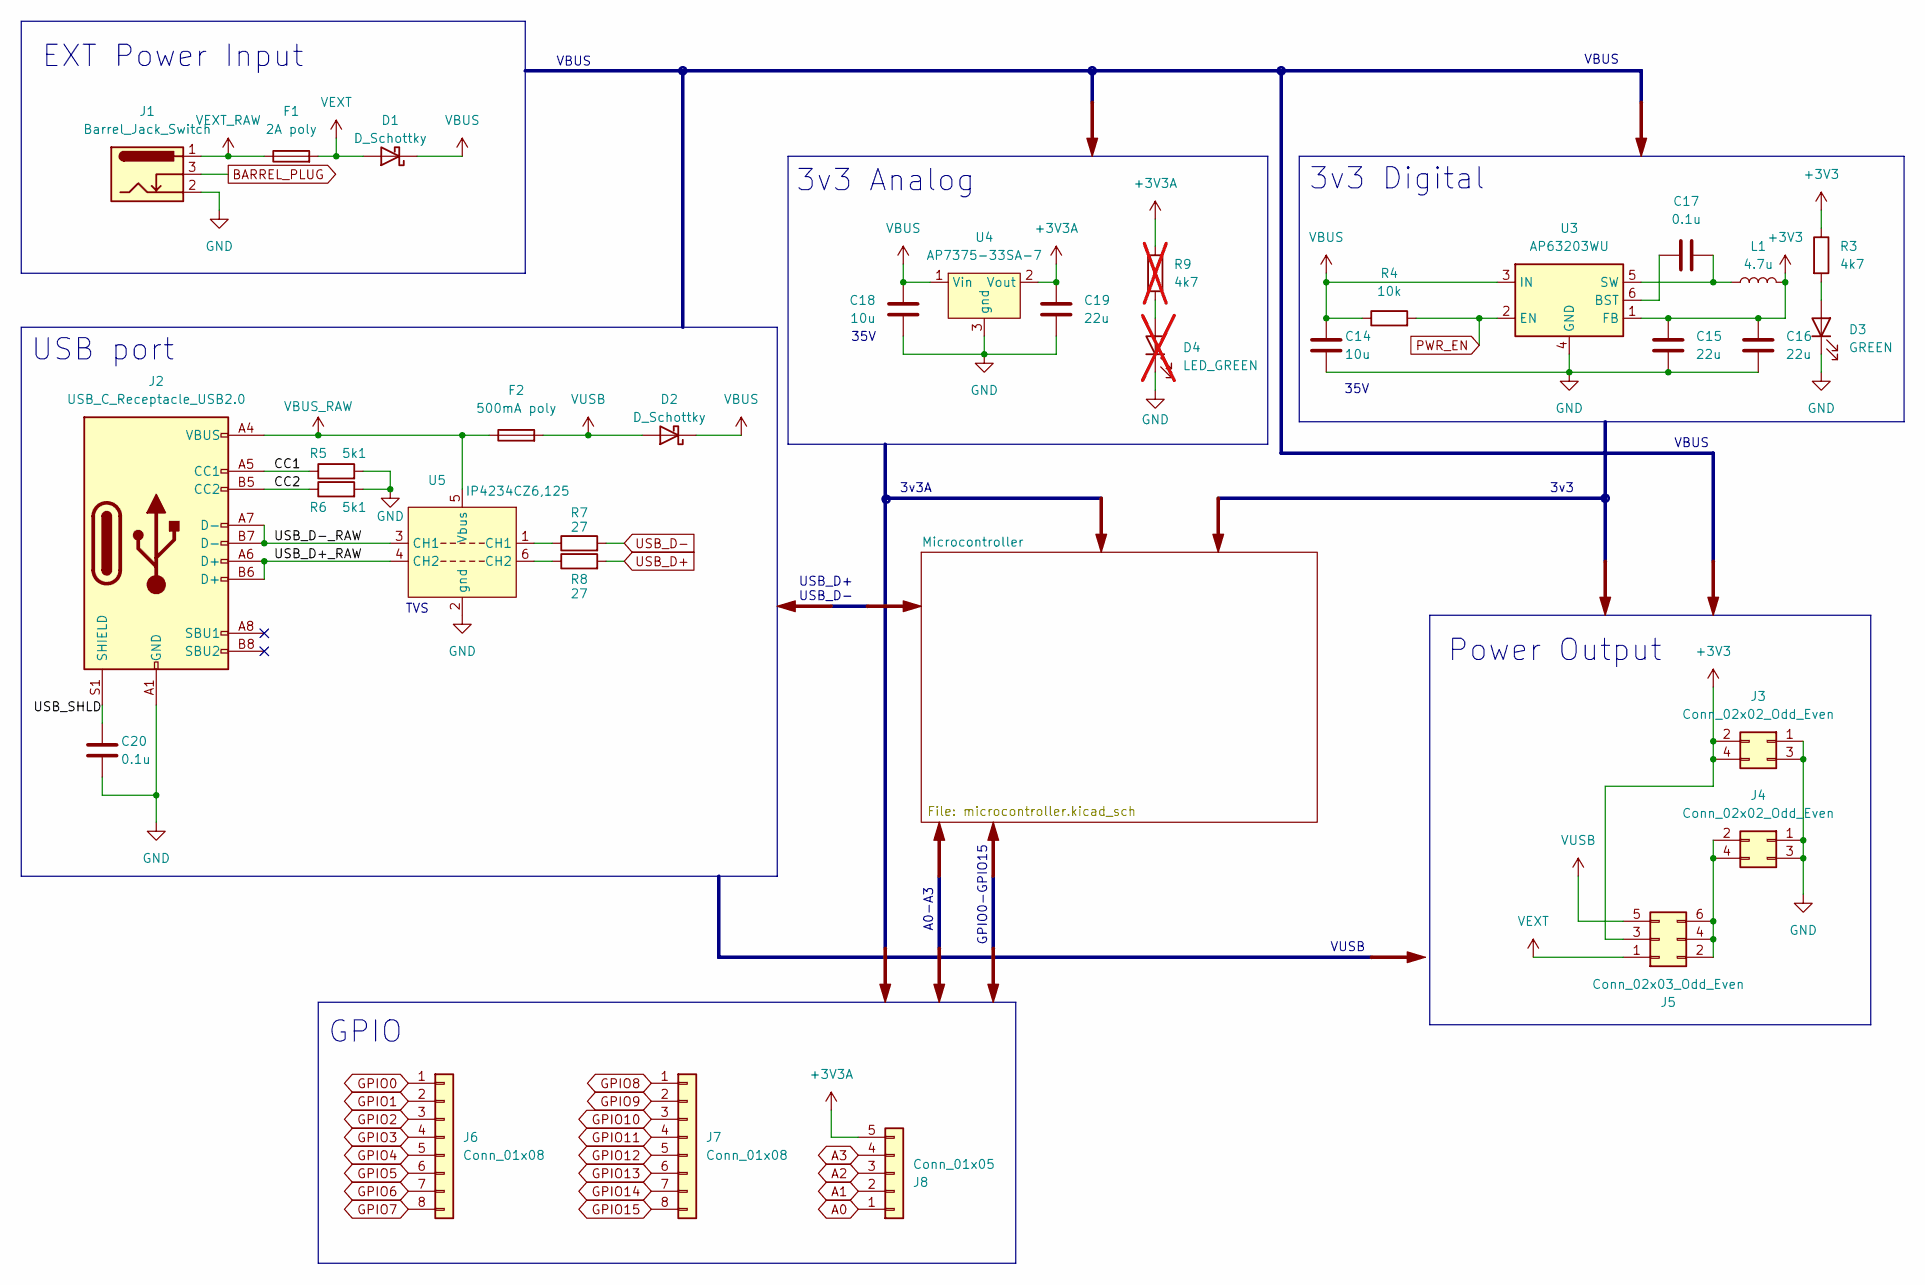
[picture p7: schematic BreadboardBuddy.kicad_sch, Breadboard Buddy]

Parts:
C14, C18: 10u; C_0603_1608Metric; MPN GRM188R6YA106MA73D
C15, C16, C19: 22u; C_0603_1608Metric; MPN GRM188R60J226MEA0D
C17, C20: 0.1u; C_0603_1608Metric; MPN CL10B104KO8NFNC
D1, D2: D_Schottky; D_1206_3216Metric; MPN SD1206S040S2R0
D3: GREEN; LED_0603_1608Metric; MPN B1911NG--20D000214U1930
D4: LED_GREEN; LED_0603_1608Metric; MPN B1911PG--20D000514U1930; not fitted
F1: 2A poly; Fuse_1206_3216Metric; MPN 1210L110/16WR
F2: 500mA poly; Fuse_1206_3216Metric; MPN 1206L025YR
J1: Barrel_Jack_Switch; BarrelJack_Wuerth_6941xx301002; MPN PJ-002A
J2: USB_C_Receptacle_USB2.0; USB_C_Receptacle_Palconn_UTC16-G; MPN 2073-USB4105-GF-ACT-ND
J3, J4: Conn_02x02_Odd_Even; PinHeader_2x02_P2.54mm_Vertical; MPN CONN HEADER VERT 4POS 2.54MM
J5: Conn_02x03_Odd_Even; PinHeader_2x03_P2.54mm_Vertical; MPN PH2-06-UA
J6, J7: Conn_01x08; PinHeader_1x08_P2.54mm_Vertical; MPN PH1-08-UA
J8: Conn_01x05; PinHeader_1x05_P2.54mm_Vertical; MPN PH1-05-UA
L1: 4.7u; L_1210_3225Metric; MPN SRP3212-4R7M
R3: 4k7; R_0603_1608Metric; MPN RMCF0603FT470R
R4: 10k; R_0603_1608Metric; MPN RMCF0603FT10K0
R5, R6: 5k1; R_0603_1608Metric; MPN RMCF0603FT5K10
R7, R8: 27; R_0603_1608Metric; MPN CR0603-FX-27R0ELF
R9: 4k7; R_0603_1608Metric; MPN RMCF0603FT470R; not fitted
U3: AP63203WU; TSOT-23-6; MPN AP63203WU-7
U4: AP7375-33SA-7; SOT-23; MPN AP7375-33SA-7
U5: IP4234CZ6,125; TSOP-6_1.65x3.05mm_P0.95mm; MPN IP4234CZ6,125

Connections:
+3V3: C15.1, C16.1, J3.2, J3.4, J5.3, L1.2, R3.1, U3.1 (FB); also elsewhere on the board
+3V3A: C19.1, J8.5, R9.1, U4.2 (Vout); also elsewhere on the board
/CC1: J2.A5 (CC1), R5.1
/CC2: J2.B5 (CC2), R6.1
/USB_D+_RAW: J2.A6 (D+), J2.B6 (D+), U5.4 (CH2)
/USB_D-_RAW: J2.A7 (D-), J2.B7 (D-), U5.3 (CH1)
/USB_SHLD: C20.1, J2.S1 (SHIELD)
A0: J8.1; also elsewhere on the board
A1: J8.2; also elsewhere on the board
A2: J8.3; also elsewhere on the board
A3: J8.4; also elsewhere on the board
BARREL_PLUG: J1.3; also elsewhere on the board
GND: C14.2, C15.2, C16.2, C18.2, C19.2, C20.2, D3.1 (K), D4.1 (K), J1.2, J2.A1 (GND), J2.A12 (GND), J2.B1 (GND), J2.B12 (GND), J3.1, J3.3, J4.1, J4.3, R5.2, R6.2, U3.4 (GND), U4.3 (gnd), U5.2 (gnd); also elsewhere on the board
GPIO0: J6.1; also elsewhere on the board
GPIO1: J6.2; also elsewhere on the board
GPIO2: J6.3; also elsewhere on the board
GPIO3: J6.4; also elsewhere on the board
GPIO4: J6.5; also elsewhere on the board
GPIO5: J6.6; also elsewhere on the board
GPIO6: J6.7; also elsewhere on the board
GPIO7: J6.8; also elsewhere on the board
GPIO8: J7.1; also elsewhere on the board
GPIO9: J7.2; also elsewhere on the board
GPIO10: J7.3; also elsewhere on the board
GPIO11: J7.4; also elsewhere on the board
GPIO12: J7.5; also elsewhere on the board
GPIO13: J7.6; also elsewhere on the board
GPIO14: J7.7; also elsewhere on the board
GPIO15: J7.8; also elsewhere on the board
unnamed: D3.2 (A), R3.2
unnamed: D4.2 (A), R9.2
unnamed: J4.2, J4.4, J5.2, J5.4, J5.6
unnamed: R7.1, U5.1 (CH1)
unnamed: R8.1, U5.6 (CH2)
unnamed: C17.1, U3.6 (BST)
unnamed: C17.2, L1.1, U3.5 (SW)
PWR_EN: R4.2, U3.2 (EN)
USB_D+: R8.2; also elsewhere on the board
USB_D-: R7.2; also elsewhere on the board
VBUS: C14.1, C18.1, D1.1 (K), D2.1 (K), R4.1, U3.3 (IN), U4.1 (Vin)
VBUS_RAW: F2.1, J2.A4 (VBUS), J2.A9 (VBUS), J2.B4 (VBUS), J2.B9 (VBUS), U5.5 (Vbus)
VEXT: D1.2 (A), F1.2, J5.1
VEXT_RAW: F1.1, J1.1
VUSB: D2.2 (A), F2.2, J5.5

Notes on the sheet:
35V
VBUS
USB port
GPIO0-GPIO15
3v3 Analog
3v3 Digital
Power Output
USB_D+ USB_D-
3v3A
TVS
GPIO
EXT Power Input
A0-A3
3v3
VUSB

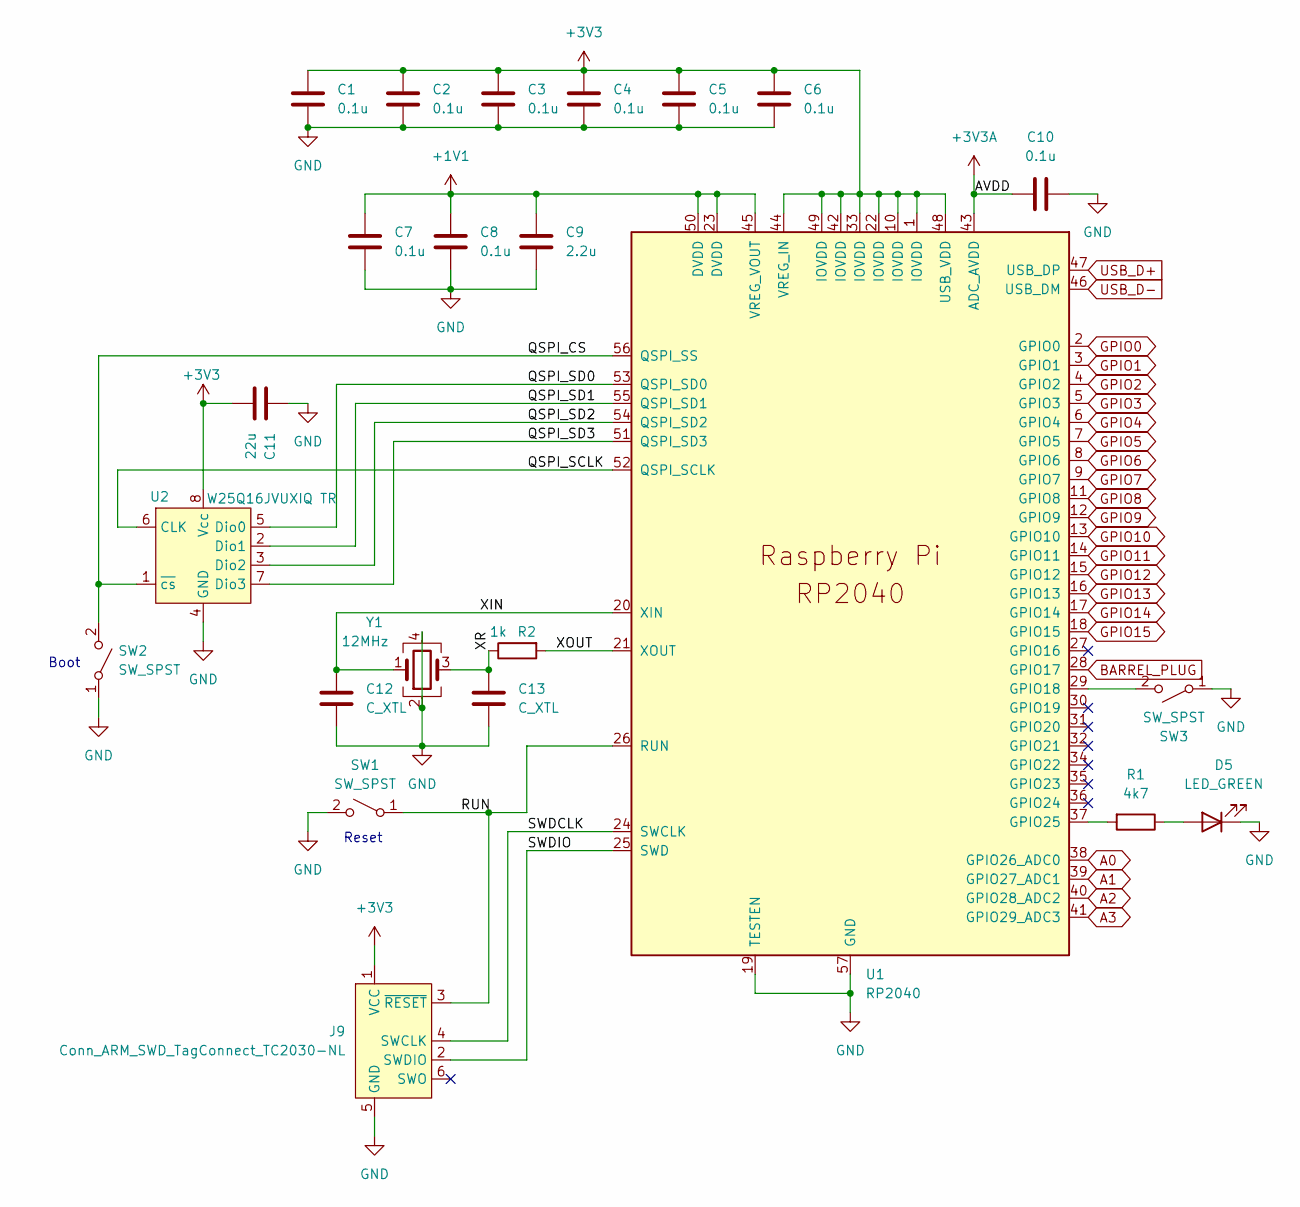
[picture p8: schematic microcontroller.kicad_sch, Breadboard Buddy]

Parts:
C1, C2, C3, C4, C5, C6, C7, C8, C10: 0.1u; C_0603_1608Metric; MPN CL10B104KO8NFNC
C9: 2.2u; C_0603_1608Metric; MPN CL10A225KP8NNNC
C11: 22u; C_0603_1608Metric; MPN GRM188R60J226MEA0D
C12, C13: C_XTL; C_0603_1608Metric; MPN 0603N150J500CT
D5: LED_GREEN; LED_0603_1608Metric; MPN B1911PG--20D000514U1930
J9: Conn_ARM_SWD_TagConnect_TC2030-NL; Tag-Connect_TC2030-IDC-NL_2x03_P1.27mm_Vertical
R1: 4k7; R_0603_1608Metric; MPN RMCF0603FT470R
R2: 1k; R_0603_1608Metric; MPN RMCF0603FT1K00
SW1, SW2, SW3: SW_SPST; SW_SPST_3.3x3.1; MPN LS38J2F-T
U1: RP2040; QFN-56-1EP_7x7mm_P0.4mm_EP3.2x3.2mm_ThermalVias; MPN SC0914(13)
U2: W25Q16JVUXIQ TR; 8-UFDFN; MPN W25Q16JVUXIQ TR
Y1: 12MHz; Crystal_SMD_3225-4Pin_3.2x2.5mm; MPN RH100-12.000-12-1010-X-TR-NS2

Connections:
+1V1: C7.1, C8.1, C9.1, U1.23 (DVDD), U1.45 (VREG_VOUT), U1.50 (DVDD)
+3V3: C1.1, C2.1, C3.1, C4.1, C5.1, C6.1, C11.2, J9.1 (VCC), U1.1 (IOVDD), U1.10 (IOVDD), U1.22 (IOVDD), U1.33 (IOVDD), U1.42 (IOVDD), U1.44 (VREG_IN), U1.48 (USB_VDD), U1.49 (IOVDD), U2.8 (Vcc); also elsewhere on the board
+3V3A: C10.1, U1.43 (ADC_AVDD); also elsewhere on the board
/Microcontroller/QSPI_CS: SW2.2 (B), U1.56 (QSPI_SS), U2.1 (~cs)
/Microcontroller/QSPI_SCLK: U1.52 (QSPI_SCLK), U2.6 (CLK)
/Microcontroller/QSPI_SD0: U1.53 (QSPI_SD0), U2.5 (Dio0)
/Microcontroller/QSPI_SD1: U1.55 (QSPI_SD1), U2.2 (Dio1)
/Microcontroller/QSPI_SD2: U1.54 (QSPI_SD2), U2.3 (Dio2)
/Microcontroller/QSPI_SD3: U1.51 (QSPI_SD3), U2.7 (Dio3)
/Microcontroller/RUN: J9.3 (~RESET), SW1.1 (A), U1.26 (RUN)
/Microcontroller/SWDCLK: J9.4 (SWCLK), U1.24 (SWCLK)
/Microcontroller/SWDIO: J9.2 (SWDIO), U1.25 (SWD)
/Microcontroller/XIN: C12.1, U1.20 (XIN), Y1.1
/Microcontroller/XOUT: R2.2, U1.21 (XOUT)
/Microcontroller/XR: C13.1, R2.1, Y1.3
A0: U1.38 (GPIO26_ADC0); also elsewhere on the board
A1: U1.39 (GPIO27_ADC1); also elsewhere on the board
A2: U1.40 (GPIO28_ADC2); also elsewhere on the board
A3: U1.41 (GPIO29_ADC3); also elsewhere on the board
BARREL_PLUG: U1.28 (GPIO17); also elsewhere on the board
GND: C1.2, C2.2, C3.2, C4.2, C5.2, C6.2, C7.2, C8.2, C9.2, C10.2, C11.1, C12.2, C13.2, D5.1 (K), J9.5 (GND), SW1.2 (B), SW2.1 (A), SW3.1 (A), U1.19 (TESTEN), U1.57 (GND), U2.4 (GND), Y1.2, Y1.4; also elsewhere on the board
GPIO0: U1.2 (GPIO0); also elsewhere on the board
GPIO1: U1.3 (GPIO1); also elsewhere on the board
GPIO2: U1.4 (GPIO2); also elsewhere on the board
GPIO3: U1.5 (GPIO3); also elsewhere on the board
GPIO4: U1.6 (GPIO4); also elsewhere on the board
GPIO5: U1.7 (GPIO5); also elsewhere on the board
GPIO6: U1.8 (GPIO6); also elsewhere on the board
GPIO7: U1.9 (GPIO7); also elsewhere on the board
GPIO8: U1.11 (GPIO8); also elsewhere on the board
GPIO9: U1.12 (GPIO9); also elsewhere on the board
GPIO10: U1.13 (GPIO10); also elsewhere on the board
GPIO11: U1.14 (GPIO11); also elsewhere on the board
GPIO12: U1.15 (GPIO12); also elsewhere on the board
GPIO13: U1.16 (GPIO13); also elsewhere on the board
GPIO14: U1.17 (GPIO14); also elsewhere on the board
GPIO15: U1.18 (GPIO15); also elsewhere on the board
unnamed: D5.2 (A), R1.1
unnamed: SW3.2 (B), U1.29 (GPIO18)
unnamed: R1.2, U1.37 (GPIO25)
USB_D+: U1.47 (USB_DP); also elsewhere on the board
USB_D-: U1.46 (USB_DM); also elsewhere on the board

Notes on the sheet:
Reset
Boot

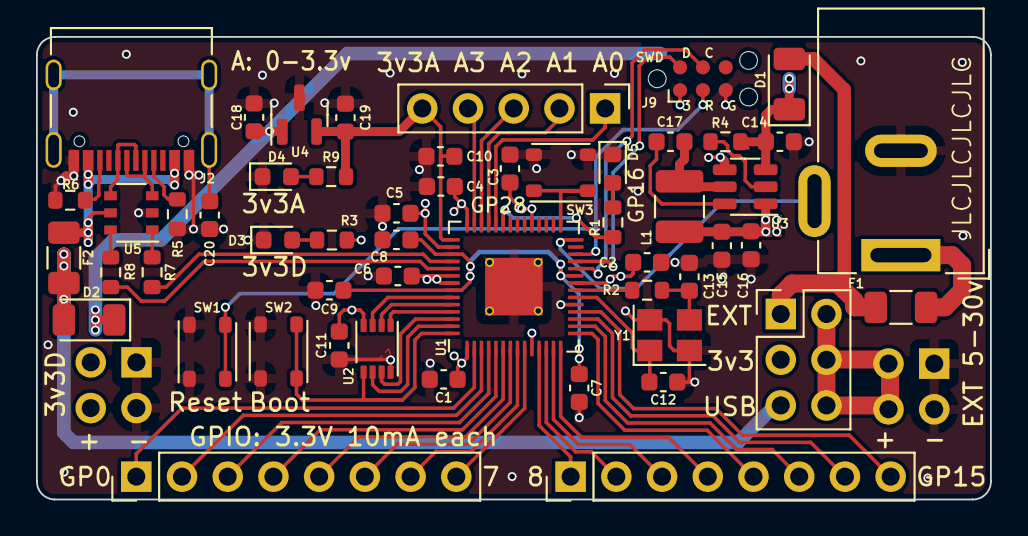
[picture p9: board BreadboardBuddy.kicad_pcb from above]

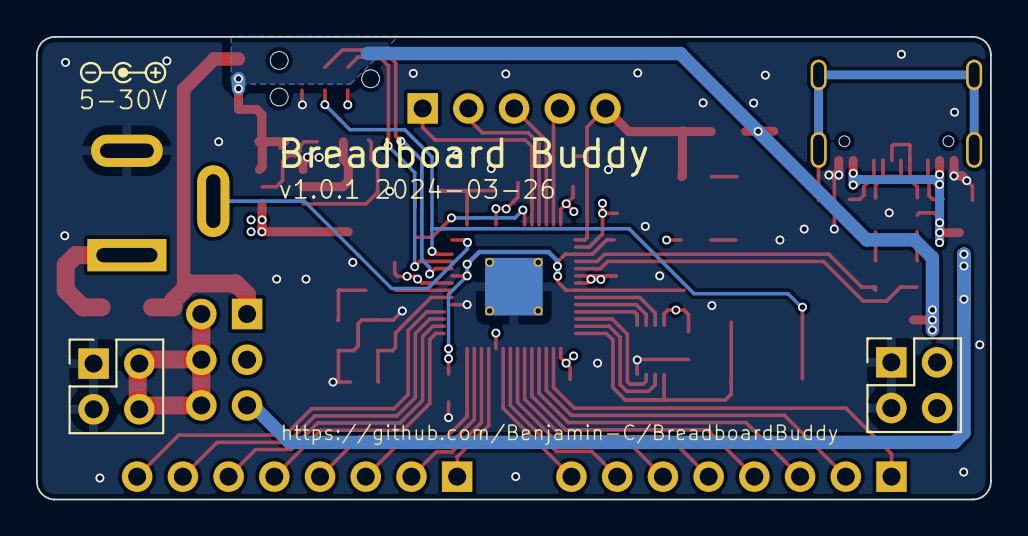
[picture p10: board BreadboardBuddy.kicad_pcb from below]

Board: 4 copper layers, 53.0 x 25.7 mm, 55 parts (2 on the bottom side), 60 nets.

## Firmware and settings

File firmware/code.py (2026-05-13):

import math
import board
import digitalio
import pwmio
import microcontroller

fwversion = "1.0.1 5/12/26"

print()

debugCmds = False

class AssignablePin():
    def __init__(self, hwpin: microcontroller.Pin, num: int):
        self.hwpin: microcontroller.Pin = hwpin
        self._num: int = num
        self._numPrefix: str = None
        self._mode = "None"
        self._strPrefix: str = ""

    @property
    def num(self):
        return self._num

    @property
    def numPrefix(self):
        return self._numPrefix

    def digitalRead(self) -> bool:
        return False
    
    def getValue(self) -> any:
        return "err"
    
    def getMode(self) -> str:
        return self._mode
    
    def __str__(self):
        return f"{self._strPrefix}{self.num}"

class DigitalPin(AssignablePin):

    MODE_OUTPUT = "OUTPUT"
    MODE_INPUT = "INPUT"
    MODE_PULLUP = "PULLUP"
    MODE_PULLDOWN = "PULLDOWN"
    MODE_PWM = "PWM"

    PWM_MAX = 65535

    def __init__(self, hwpin: microcontroller.Pin, num: int, mode: str = "input"):
        super().__init__(hwpin=hwpin, num=num)
        self._numPrefix = ""
        self._strPrefix = "Digc"
        self._mayChangeMode = True
        self._pin = None
        self._setMode(mode)
    
    @property
    def mayChangeMode(self):
        return self._mayChangeMode
    
    @property
    def mode(self):
        return self._mode
    
    @mode.setter
    def mode(self, modestr):
        self.setMode(modestr)

    def _deinit(self):
        # Deinit specific pin types
        if isinstance(self._pin, pwmio.PWMOut):
            self._pin.deinit()
        elif isinstance(self._pin, digitalio.DigitalInOut):
            self._pin.deinit()
        # Clear the pin
        self._pin = None

    def _setDIO(self):
        # Only set up if we aren't already set up
        if not isinstance(self._pin, digitalio.DigitalInOut):
            # Deinit any other existing pin modes
            self._deinit()
            # Initialize DigitalInOut
            self._pin = digitalio.DigitalInOut(self.hwpin)

    def _setPWM(self):
        # If we're not already set up as PWM
        if not isinstance(self._pin, pwmio.PWMOut):
            # Deinit any current mode
            self._deinit()
            # Initialize PWM
            self._pin = pwmio.PWMOut(self.hwpin)

    def setMode(self, modestr: str):
        ''' Sets the mode of this pin.
        Returns True if the mode was changed or if it was already the new mode
        Returns False if the mode wasn't changed due to an invalid mode
        Raises a RuntimeError if you aren't allowed to change the mode
        '''
        if self._mayChangeMode:
            return self._setMode(modestr)
        else:
            raise RuntimeError("You can't change the mode of this")
    
    def _setMode(self, modestr: str):
        modestr = modestr.upper()
        if modestr == 'OUTPUT' or modestr == "OUT":
            self._setDIO()
            self._pin.direction = digitalio.Direction.OUTPUT
            self._mode = self.MODE_OUTPUT
        elif modestr == 'INPUT' or modestr == "IN":
            self._setDIO()
            self._pin.direction = digitalio.Direction.INPUT
            self._pin.pull = None
            self._mode = self.MODE_INPUT
        elif modestr == 'PULLUP':
            self._setDIO()
            self._pin.direction = digitalio.Direction.INPUT
            self._pin.pull = digitalio.Pull.UP
            self._mode = self.MODE_PULLUP
        elif modestr == 'PULLDOWN':
            self._setDIO()
            self._pin.direction = digitalio.Direction.INPUT
            self._pin.pull = digitalio.Pull.DOWN
            self._mode = self.MODE_PULLDOWN
        elif modestr == "PWM":
            self._setPWM()
            self._mode = self.MODE_PWM
        else:
            return False
        return True

    def setValue(self, value):
        self._pin.value = value

    def getValue(self) -> any:
        return ("H" if self._pin.value else "L") if self._mode != DigitalPin.MODE_PWM else f"{self._pin.duty_cycle/self.PWM_MAX:0.3f}"
    
    def digitalRead(self) -> bool:
        if self._mode != self.MODE_PWM:
            return self._pin.value
        else:
            return self._pin.duty_cycle > self.PWM_MAX/2
    
class LEDPin(DigitalPin):
    def __init__(self, hwpin: microcontroller.Pin, num=0):
        super().__init__(hwpin=hwpin, num=num, mode="output")
        self._numPrefix = "led"
        self._strPrefix = "Led"
        self._mayChangeMode = False

class Command():
    def __init__(self):
        pass

    def onInstruction(self, pins: list[AssignablePin], names: list[str], arg: list[str]):
        self.onQuestion(pins, names, arg)

    def onQuestion(self, pins: list[AssignablePin], names: list[str], arg: list[str]):
        pass

# commands = {"help": HelpCommand(), "mode": ModeCommand(), "read": ReadCommand(), "set": SetCommand(), "binary": BinaryCommand()}


class HelpCommand(Command):
    def onQuestion(self, pins: list[AssignablePin], names: list[str], arg: list[str]):
        print(f"BreadBoard Buddy firmware v{fwversion}")
        print("Commands:")
        print("  `mode? <pins>`")
        print("  `mode <pins> <modes>`")
        print("    Gets/sets the mode of digital pins. Modes are OUTPUT, INPUT, PULLUP, PULLDOWN")
        print("  `read? <pins>`")
        print("    Reads the values from pins")
        print("  `set <pins> <values>`")
        print("    Sets the values of digital pins")
        print("  `binary? <pins> [base]`")
        print("  `binary <pins> <value> [base]`")
        print("    Gets/sets pins to a value optionally in a given base. Bases are BIN, OCT, DEC, HEX.")
        print("    Pins are specified MSB first, and numbers may be truncated from the MSB end if needed")
        print("Pins can be specified as:")
        print("  Numbers. Valid numbers are 0-15, LED")
        print("  Ranges with a start and end pin seperated by a dash. Pins will be used in the order specified")
        print("  Comma seperated lists combining any of the above")
        print("  EX: 1,5,8-15")
        print("")
        print("Visit https://github.com/Benjamin-C/BreadboardBuddy/blob/main/docs/docs.pdf")

class ModeCommand(Command):
    def onInstruction(self, pins, names, arg):
        # Check if any modes were given
        if len(arg) < 1:
            print("You must specify the mode to set")
            return
        # Get the list of all modes
        modes = arg[0].split(",")
        # Throw an error if there is an invalid number of errors.
        if len(modes) < 0 or (len(modes) != 1 and len(modes) != len(pins)):
            print("You must specify either a single mode for all pins, or a mode for each pin")
            print("There was a fatal error, aborting")
            return
        # Try to set the mode for each pin
        changed = False
        for i in range(len(pins)):
            pin = pins[i]
            # Check if the pins are digital
            if isinstance(pin, DigitalPin):
                # Set the mode or say why we can't
                try:
                    if pin.setMode(modes[i] if len(modes) > 1 else modes[0]):
                        changed = True
                    else:
                        print(f"Invalid mode for pin {names[i]}, skipping")
                        continue
                except:
                    print(f"You can't change the mode for pin {names[i]}, skipping")
                    continue
            else:
                print(f"Pin {names[i]} is not digital, skipping")
                continue
        if changed:
            print("OK")
    
    def onQuestion(self, pins, names, arg):
        # Print the mode of all pins
        print(",".join([p.getMode() for p in pins]))

class DigitalCommand(Command):
    def __init__(self):
        super().__init__()
        self.setcmd = SetCommand()

    def onInstruction(self, pins: list[AssignablePin], names: list[str], arg: list[str]):
        self.setcmd.onInstruction(pins, names, arg)
    
    def onQuestion(self, pins: list[AssignablePin], names: list[str], arg: list[str]):
        answer = ""
        for i in range(len(pins)):
            pin = pins[i]
            # Check if the pins are digital
            if isinstance(pin, DigitalPin):
                answer += "H" if pin.digitalRead() else "L"
        print(answer)

class ReadCommand(Command):
    def onQuestion(self, pins: list[AssignablePin], names: list[str], arg: list[str]):
        print(",".join([p.getValue() for p in pins]))
        return super().onQuestion(pins, names, arg)
    
class SetCommand(Command):
    def onInstruction(self, pins: list[AssignablePin], names: list[str], arg: list[str]):
        # Check if any modes were given
        if len(arg) < 1:
            print("You must specify the mode to set")
            return
        # Get the list of all modes
        values = arg[0].split(",")
        # Throw an error if there is an invalid number of errors.
        if len(values) < 0 or (len(values) != 1 and len(values) != len(pins)):
            print("You must specify either a single mode for all pins, or a mode for each pin")
            print("There was a fatal error, aborting")
            return
        # Try to set the mode for each pin
        changed = False
        for i in range(len(pins)):
            pin = pins[i]
            val = values[i] if len(values) > 1 else values[0]
            # Check if the pins are digital
            if isinstance(pin, DigitalPin):
                # Set the mode or say why we can't
                if pin.mode == DigitalPin.MODE_OUTPUT:
                    v = parseHighLow(val)
                    if v is not None:
                        pin.setValue(v)
                        changed = True
                        continue
                    else:
                        print(f"Invalid value {val} for pin {names[i]}, skipping")
                        continue
                elif pin.mode == DigitalPin.MODE_PWM:
                    v = parseHighLow(val)
                    if v is not None:
                        pin.setValue(DigitalPin.PWM_MAX if v else 0)
                        changed = True
                        continue
                    else:
                        print(f"Invalid value {val} for pin {names[i]}, skipping")
                        continue
                else:
                    # Setting input pins has no effect
                    continue
            else:
                print(f"Pin {names[i]} is not digital, skipping")
                continue
        if changed:
            print("OK")

    def onQuestion(self, pins: list[AssignablePin], names: list[str], arg: list[str]):
        print('Use "read" to read from pins')

class BinaryCommand(Command):
    def calcBase(self, arg):
        ''' Reads the base from the first element of the array, or returns 2 if it doesn't exist or isn't on the list '''
        base = 2
        if len(arg) > 0:
            arg[0] = arg[0].upper()
            if arg[0] == 'DEC':
                base = 10
            elif arg[0] == 'HEX':
                base = 16
            elif arg[0] == 'OCT':
                base = 8
            elif arg[0] == 'BIN':
                base = 2
            else:
                print("Unknown base specified, assuming binary.")
        return base
    
    def onInstruction(self, pins: list[AssignablePin], names: list[str], arg: list[str]):
        # Check we have a number
        if len(arg) == 0:
            print('You must specify a value to set, or use "binary?" to read values. Aborting.')
            return
        # Get the base
        base = self.calcBase(arg[1:])
        # Parse the value from the given base
        value = 0
        try:
            value = int(arg[0], base)
        except:
            print(f"Invalid number {arg[0]} for base {base}. Aborting.")
            return
        # Check we can write to all the pins
        for i in range(len(pins)):
            if not isinstance(pins[i], DigitalPin):
                print(f"Pin {names[i]} is not a writable pin. Aborting.")
                return
        # Write to the pins, MSB first
        for pin in pins[::-1]:
            pin.setValue(value % 2)
            value //= 2
        print("OK")
    
    def onQuestion(self, pins: list[AssignablePin], names: list[str], arg: list[str]):
        # Get the desired base
        base = self.calcBase(arg)
        # Calculate how many digits to pad to
        digitCount = math.ceil(math.log(2**len(pins), base))
        # Read the value
        value = 0
        for pin in pins:
            value <<= 1
            value |= 1 if pin.digitalRead() else 0
        # Print the value
        answer = ""
        for i in range(digitCount):
            d = value % base
            value //= base
            answer = "0123456789ABCDEF"[d] + answer
        print(answer)

# List of all possible commands
commands = {"help": HelpCommand(), "mode": ModeCommand(), "read": ReadCommand(), "set": SetCommand(), "binary": BinaryCommand()}

def parseHighLow(val):
    if val.upper() in ["H", "HIGH", "1", "ON"]:
        return True
    elif val.upper() in ["L", "LOW", "0", "OFF"]:
        return False
    else:
        return None

# Add the pins
pinsByNumber = {}
for i in range(15+1):
    exec(f"pinsByNumber['{i}'] =  DigitalPin(board.GP{i}, {i})")
pinsByNumber['26'] = DigitalPin(board.GP26, 26)
pinsByNumber["led"] = LEDPin(board.LED)

for i in range(4):
    # TODO analog pins go here
    pass

pinsByName = {"d0": pinsByNumber["0"], "d1": pinsByNumber["1"], "d2": pinsByNumber["2"], "d3": pinsByNumber["3"]}

def getPin(name: str) -> AssignablePin:
    # Check if the pin is referenced by number
    name = name.lower()
    if name in pinsByNumber:
        return pinsByNumber[name]
    # Then check if the pin is being specified by a nickname
    elif name in pinsByName:
        return pinsByName[name]
    # If neither, return none
    return None

# testCmds = ["mode? d0-d3,7,9-12,LED", "mode d0-d3,7,LED OUT", "mode 9-12 OUT,OUT,IN,PULLUP", "mode? d0-d3,7,9-12,LED"]
testCmds = ["mode 0-3 output", "set 0-3 h,h,l,l", "read 0-3", "binary? 0-3"]

while True:
    # Get the user's input
    cmd = input("BB> ")
    # if len(testCmds) > 0:
    #     cmd = testCmds[0]
    #     testCmds = testCmds[1:]
    #     print("CMD=" + cmd)

    # Prep variables to parse the command into
    verb = ""
    isQuestion = False
    pins = []
    pinNames = []
    args = []
    error = False
    
    # Parse the command
    words = cmd.split(" ")
    if len(words) >= 1:
        # Collect the verb from the command
        verb = words[0]
        if len(verb) > 0 and verb[-1] == '?':
            isQuestion = True
            verb = verb[:-1]
    if len(words) >= 2:
        # Collect the pins from the command
        for pn in words[1].split(","):
            # First check if the pin was specified by a range
            if '-' in pn:
                # Find the bounds of the range
                bounds = pn.split("-")
                a = getPin(bounds[0])
                b = getPin(bounds[1])
                if a is not None and b is not None:
                    # Make sure the bounds of the range are of the same type
                    if a.numPrefix == b.numPrefix and a.numPrefix is not None:
                        # Add all pins in the range to the pin list
                        for i in range(a.num, b.num+1):
                            # Get the next pin in the range
                            p = getPin(a.numPrefix + str(i))
                            # Make sure that it exists, and error if not
                            if p is not None:
                                pins.append(p)
                                if i == a.num:
                                    pinNames.append(bounds[0])
                                elif i == b.num:
                                    pinNames.append(bounds[1])
                                else:
                                    pinNames.append(p.numPrefix + str(p.num))
                            else:
                                print(f"Invalid pin in range {pn}")
                                error = True
                                break
                        # Added pins, so go to next list item
                        continue
                    # The bounds were not of the same type
                    else:
                        print(f"Invalid range {pn}. You may not mix pin types in a range.")
                        error = True
                        break
                else:
                    print(f"One of the bounds of the range {pn} is invalid")
                    error = True
                    break
            # The pin was not specified by range
            else:
                # Try to get the pin by name or number
                p = getPin(pn)
                # If it exists, add it and go to the next list item
                if p is not None:
                    pins.append(p)
                    pinNames.append(pn)
                    continue
                # If it doesn't exist, throw an error
                else:
                    print(f"Invalid pin name {pn}")
                    error = True
                    break
    if len(words) >= 3:
        # Collect any additional arguments from the command
        args = words[2:]

    if debugCmds:
        print(f"CMD:{verb} Q?{isQuestion} PIN:{len(pins)}[{','.join([str(p) for p in pins])}] PN:{pinNames} ARGS:{args}")

    # Only execute the command if it could be parsed correctly
    if error:
        print("An error occurred during the parsing of the command, aborting")
        continue
    if verb in commands:
        try:
            if isQuestion:
                commands[verb].onQuestion(pins, pinNames, args)
            else:
                commands[verb].onInstruction(pins, pinNames, args)
        except Exception as e:
            print("There was an error execuing the command.")
            print("If the command acted on multiple pins, some may not have been done")
            print("Running the command individually on each pin may help find the issue")
            if debugCmds:
                print("Error:", e)
    else:
        print('Please tell me what to do. You can ask "help?" if you need help.')

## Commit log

2024-03-10 Created PCB
    [BreadboardBuddy.kicad_pcb, BreadboardBuddy.kicad_sch, connectors.kicad_sch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]
2024-03-11 Added command and power docs
2024-03-11 Prepped for DR
    [BreadboardBuddy.kicad_pcb, BreadboardBuddy.kicad_sch, connectors.kicad_sch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]
2024-03-12 Prepared for fab
    [BreadboardBuddy.kicad_pcb, BreadboardBuddy.kicad_sch, microcontroller.kicad_sch]
2024-04-21 Fixed board USB issue
    [BreadboardBuddy.kicad_pcb, BreadboardBuddy.kicad_sch]
2024-04-21 Improved flash footprint
    [BreadboardBuddy.kicad_pcb]
